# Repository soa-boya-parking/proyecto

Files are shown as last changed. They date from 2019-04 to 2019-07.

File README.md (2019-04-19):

# Proyecto Sistemas Operativos Avanzados 1C 2019 

### Integrantes

- Ezequiel Laurenti - 39245012
- Hector Rojas Stoll - 94448064
- Juan Jose Tocino - 38617339
- Damian Vinci - 30603450

## Proyecto Pileta   

El proyecto consiste en un administrador de pileta inteligente, que brindará lo siguiente:
- Detección del ingreso de un elemento a la misma y alerta del suceso.  
Esto es útil, por ejemplo, para detectar la caída accidental de una mascota a la pileta.  
- Detección de las condiciones de la pileta (temperatura) y por consiguiente dispensar la cantidad de cloro necesario
- Detección de lluvia:
  - De forma anticipada: Mediante la consulta a un servicio climatológico.
  - De forma nativa: Mediante la detección de gotas de lluvia.  
  En ambos casos será para activar un motor que despliegue una lona sobre la pileta.
- Detección de suciedad de la pileta.  

En cualquiera de los casos anteriores, se notificará mediante algunas de las conexiones disponibles (WiFi / Bluetooth)   
del suceso ocurrido.  
De cualquier manera, el usuario podrá configurar distintos parámetros manualmente desde su celular para modificar el funcionamiento, por ejemplo, la cantidad de cloro dispensada dependiendo de la cantidad de personas en la pileta.

## Especificaciones Técnicas 

**Las herramientas y tecnologías a utilizar serán:**

- SoC SparkFun ESP32
- BLE (Bluetooth Low Energy)
- Wifi (802.11 b/g/n/e/i WLAN)
- iPhone (con iOS 12.2)

**Sensores:**
 - Sensor de temperatura (DS18B20) A Prueba de agua.
 - Sensor de lluvia (FC-37 / YL-83).
 - Sensor de color (TCS3200 / TCS34725).
 - Acelerómetro (ADXL335).
 
 **Actuadores:**
  - Valvula Solenoide.
  - Buzzer.
  - Motor.

## Cerradura Electrónica  

El proyecto consiste en el control de las puertas de un hogar / establecimiento sin la utilización de llaves físicas.  
Entre las principales funciones del control de las puertas del hogar se encuentran:
- Detección del estado de la/s puerta/s (abierta - cerrada) 
- Apertura y/o cierre de la/s puerta/s 
- Programación del cierre y/o apertura de la/s puerta/s a un determinado horario.
- Apertura de la puerta por proximidad mediante un dispositivo asociado.
- Informe sobre un intento no autorizado y/o violento.

Todas las acciones anteriores serán accedidas mediante un dispositivo asociado (celular)   
de forma inalámbricamente (Wifi y Bluetooth)

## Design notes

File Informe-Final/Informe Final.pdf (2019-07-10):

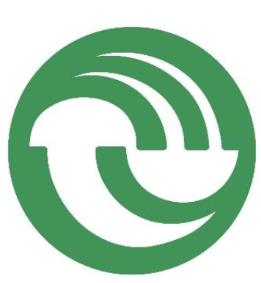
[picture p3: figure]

# Universidad Nacional de La Matanza

## Departamento de Ingeniería e Investigaciones Tecnológicas

# Sistemas Operativos Avanzados Proyecto Boya-Parking

# Informe Final

# Docentes:

## - Graciela de Luca - Waldo A. Valiente - Sebastián Barillaro - Mariano Volker - Carnuccio, Esteban Andrés - Gerardo Garcia

# Integrantes:

## - Héctor Rojas Stoll - Juan Jose Tocino - Ezequiel Laurenti - Damián Vinci

Índice

# Motivación del proyecto

La administración desatendida de una piscina mediante el uso de una boya inteligente y un dispositivo móvil, buscando ayudar al usuario final en la toma de decisiones al momento de realizar tareas de mantenimiento. Además, permitirá la automatización de determinadas funciones, delegando completamente la responsabilidad a la boya inteligente. La misma tendrá la capacidad de ejecutarlas en base a información recolectada del entorno mediante diversos sensores y además “aprendiendo” sobre condiciones pasadas, se espera que pueda cumplir los siguientes objetivos:

## - Apertura y / o cierre del techo de la piscina

- Automáticamente, dependiendo de los factores climatológicos.
- A demanda y de forma remota, a través de un dispositivo móvil.

## - Dispensación de cloro - De manera automática en un horario fijado por el usuario, en base a condiciones como temperatura actual, capacidad de la pileta siempre

y cuando se detecte a la pileta vacía (Sin personas dentro).
- A demanda y de forma remota, a través de un dispositivo móvil.
- Recibir alertas a un dispositivo móvil sobre la caída de un objeto a la piscina.

## - Monitoreo desde el dispositivo móvil en tiempo real del estado de la piscina

como la temperatura y el nivel de opacidad del agua.

# Software Utilizado

## - Arduino IDE 1.8.9 (C / C++) - Xcode 10.2.1 (Swift 5) - Servidor Web Lampp PHP 7 (Api Clima Mock)

# Componentes

# SoC (System on Chip)

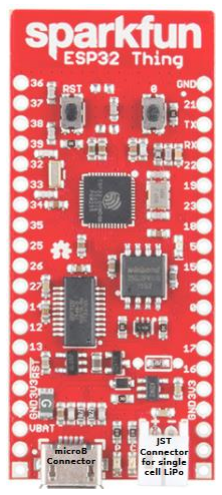
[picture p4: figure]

- Dual-core Xtensa 32-bit LX6 240MHZ.
- 520kB internal SRAM.
- 4MB external flash.
- Wireless 802.11 b/g/n/e/I WPA/WPA2.
- Bluetooth 4.2 / BLE.
- VCC Range: 2.2V ~ 3.6V.
- SPI, I2C, ART, I2S Interfaces.

# Sensores

## Acelerómetro ADXL345 (Digital)

- Sensor micromecanizado (MEMS) capacitivo.
- 3 ejes independientes.
- Compatibles con interfaces SPI y I2C.
- Rango de medición ajustable ±2g, ±4g, ±8g, ±16g.

## Colorímetro TCS34725 (Digital)

- Sensor de color digital.
- Proporciona los valores RGB y clear medición sin filtrar.
- Compatible con interfaz I2C.

## - Cuenta con un rango dinámico 3,800,000:1

## Sensor de temperatura DS18B20 Versión Sonda Impermeable (Digital)

- Sensor de temperatura digital.
- Rango de temperaturas: -55°C hasta los 125°C.
- Compatible con interfaz 1-wire (Un solo pin de datos).

## - Precisión ±0.5°C desde -10°C a +85°C

## Sensor detector de lluvia FC-37 (Digital / Analógico)

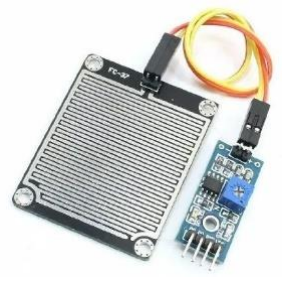
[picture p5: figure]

## - Sensor de detección de agua por variación de

conductividad.
•Permite la lectura de forma analógica o digital. •Posee dos partes el sensor y el controlador.

# Actuadores

## Motor DC RE280

- 9000 revoluciones por minuto.
- Tensión de trabajo 1.5V ~ 3V.

## Doble Puente H Driver L9110s

- Puede manejar 2 motores simultáneamente.
- Basado en el microcontrolador L9110.

## Electroválvula

- Tensión de trabajo 220V.
- Tipo normal – cerrada.

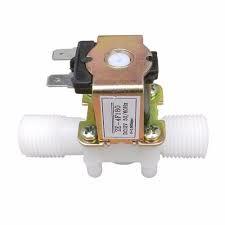
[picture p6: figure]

## Otros Relé El relé es un dispositivo electromagnético. Funciona como un interruptor controlado por un circuito eléctrico en el que, por medio de una bobina y un electroimán, se acciona un juego de uno o varios contactos que permiten abrir o cerrar

otros circuitos eléctricos independientes.

## Transistor El transistor es un dispositivo electrónico semiconductor utilizado para entregar una señal de salida en respuesta a una

señal de entrada.

## Resistor El resistor es un componente electrónico diseñado para introducir una resistencia eléctrica determinada entre dos

puntos del circuito eléctrico.

## Protoboard Es un tablero con orificios que se encuentran conectados eléctricamente entre sí de manera interna, en el cual se pueden insertar componentes electrónicos y cables para el

armado y prototipado de circuitos electrónicos.

# Diagramas Diagrama Fritzing

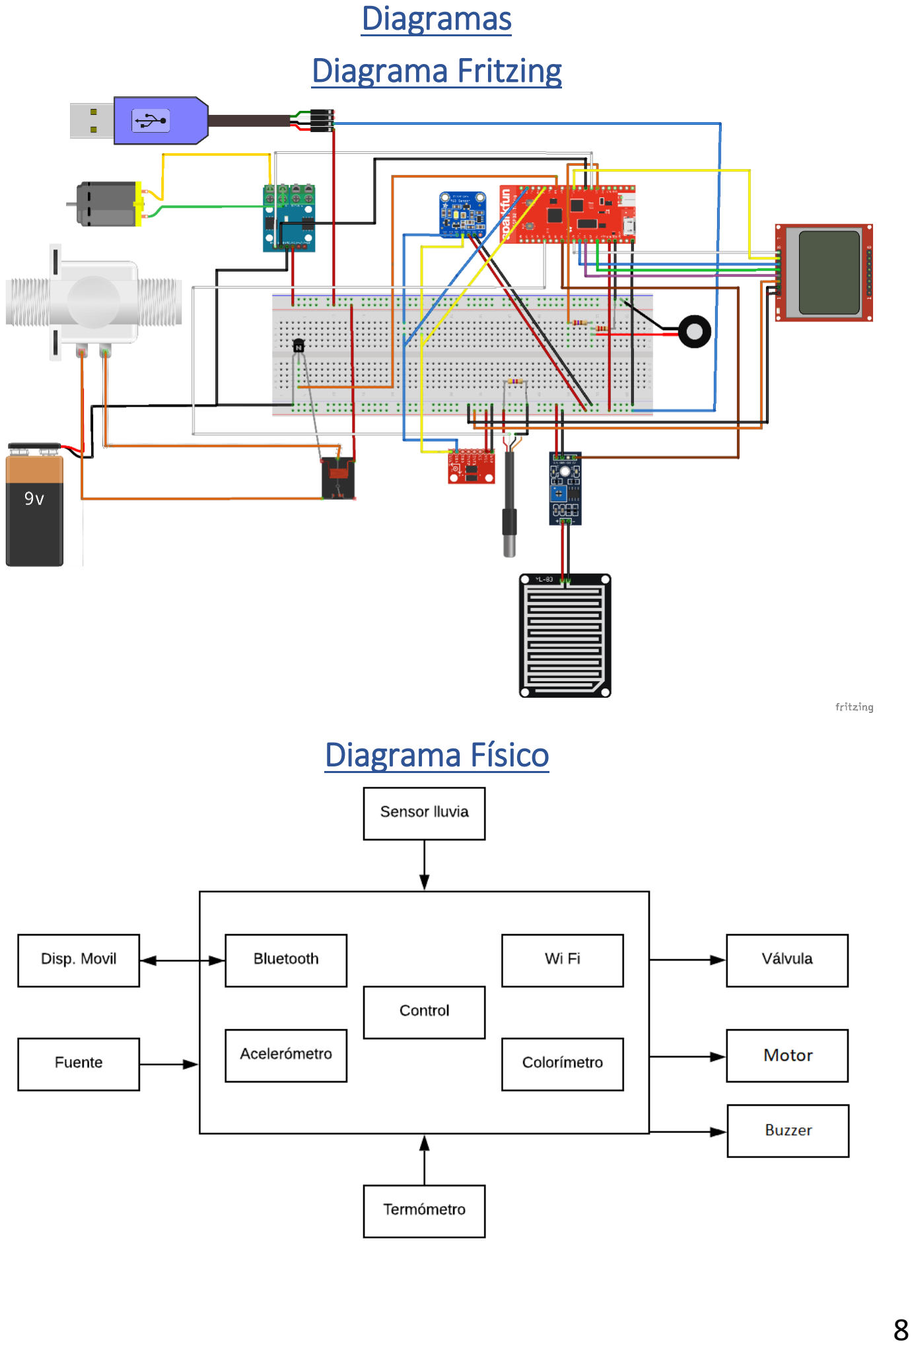
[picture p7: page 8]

# Diagrama Físico

# Diagrama Funcional

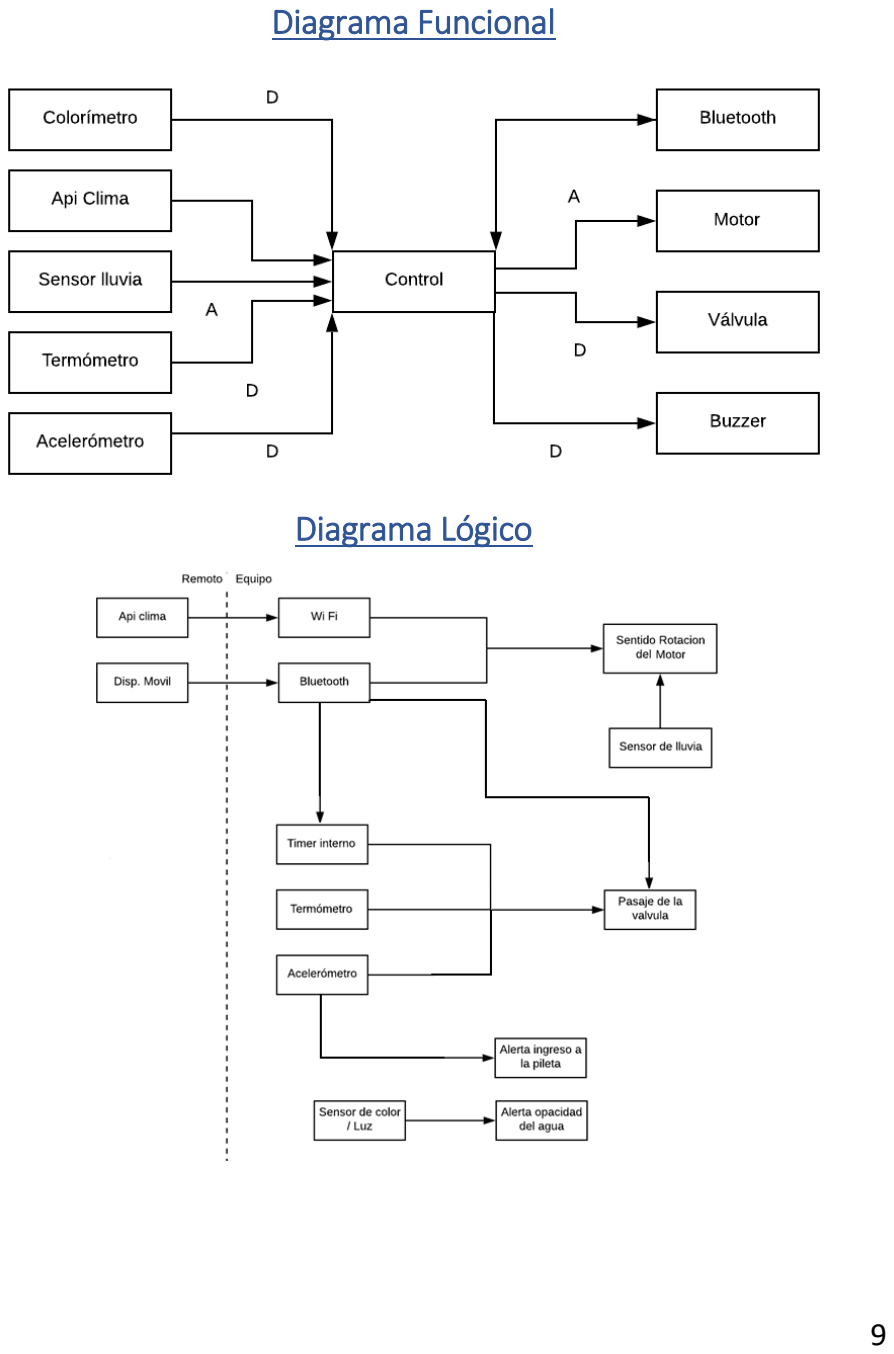
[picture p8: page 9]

# Diagrama Lógico

# Diagrama de software

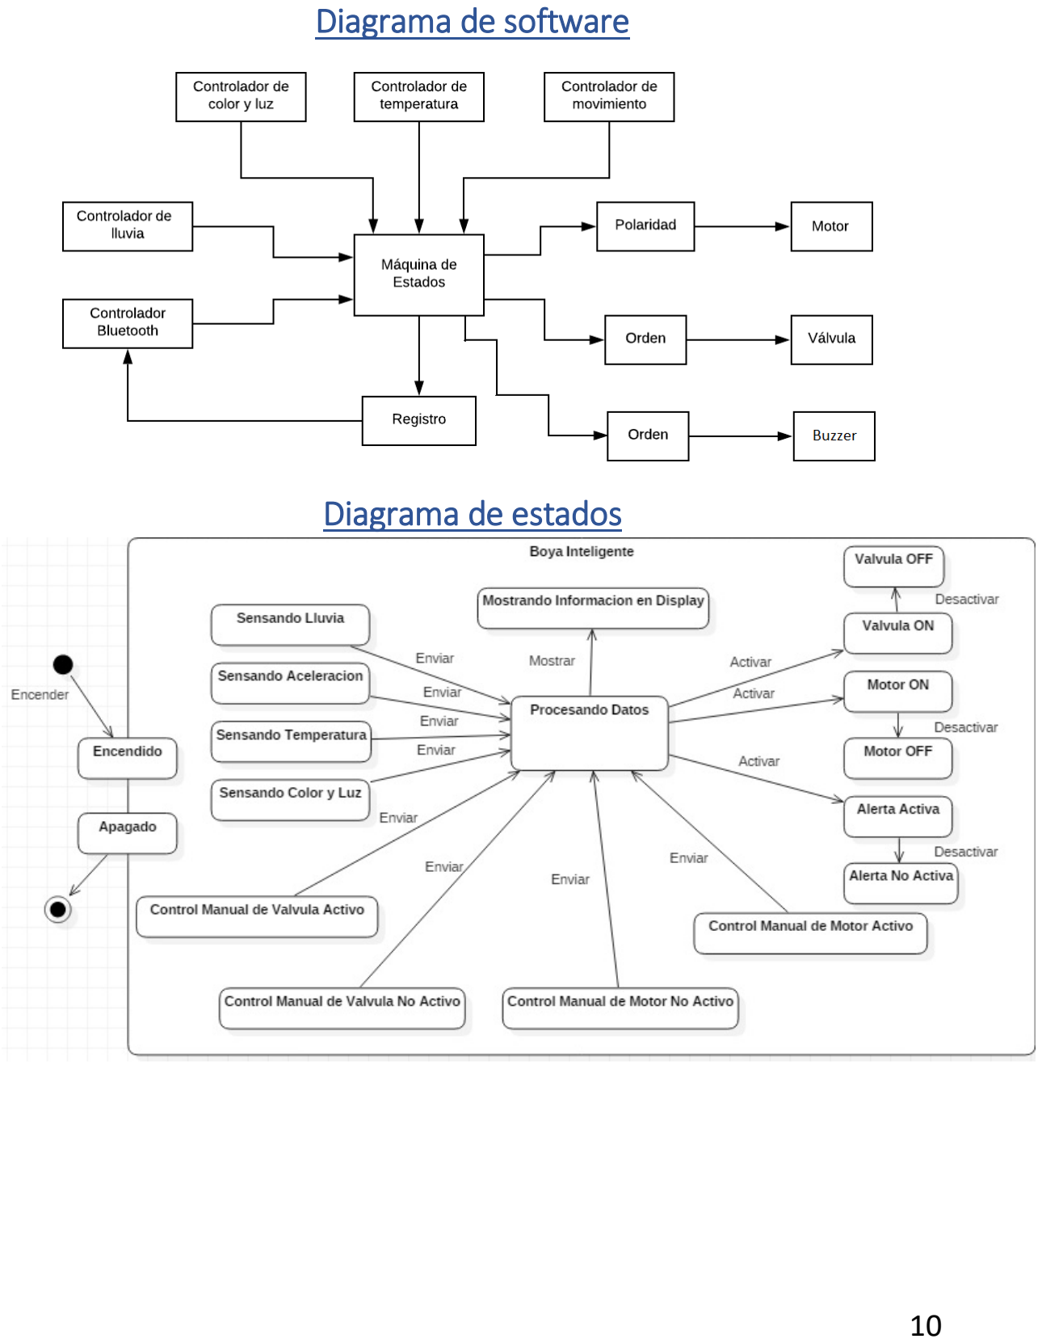
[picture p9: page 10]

# Diagrama de estados

# Diagrama En Bloques

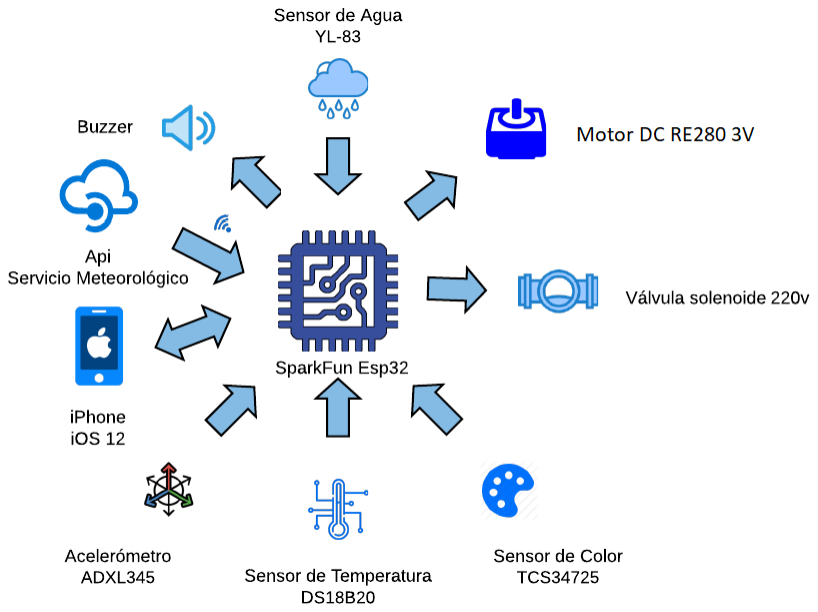
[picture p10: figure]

# Pantallas Pantalla del SE (Inicial)

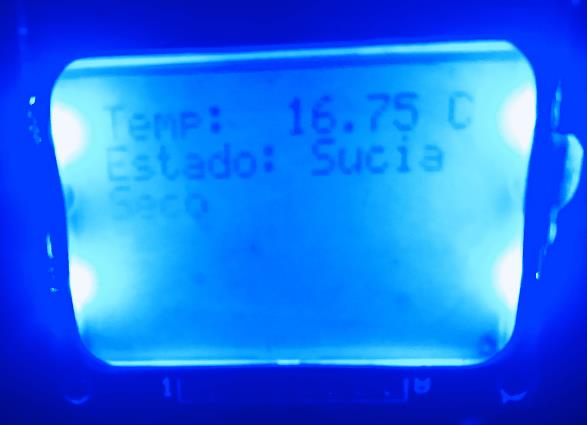
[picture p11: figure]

# Pantalla del SE (Reloj - Ubicación - Coordenadas)

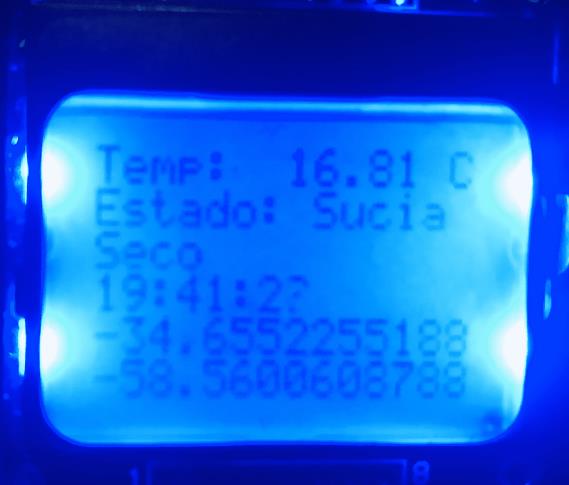
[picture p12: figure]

# Pantalla del SE (Reloj - Ubicación – Texto - Clima)

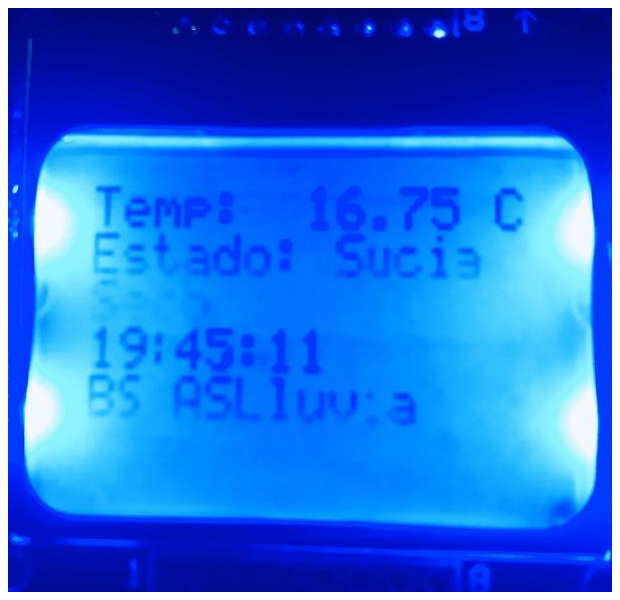
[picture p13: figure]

# Pantalla Principal de la Aplicación Mobile

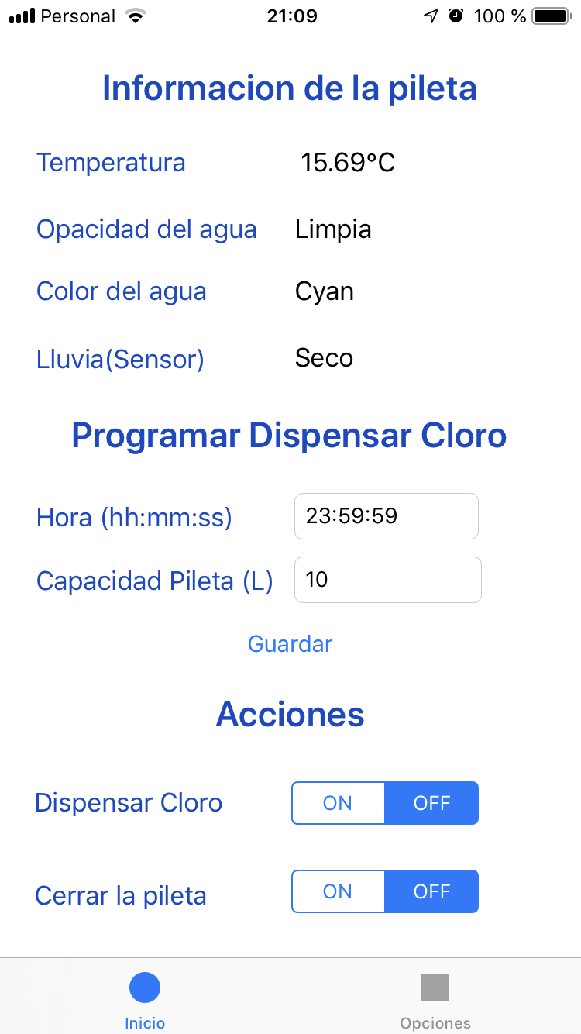
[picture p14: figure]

# Pantalla Secundaria de la Aplicación Mobile

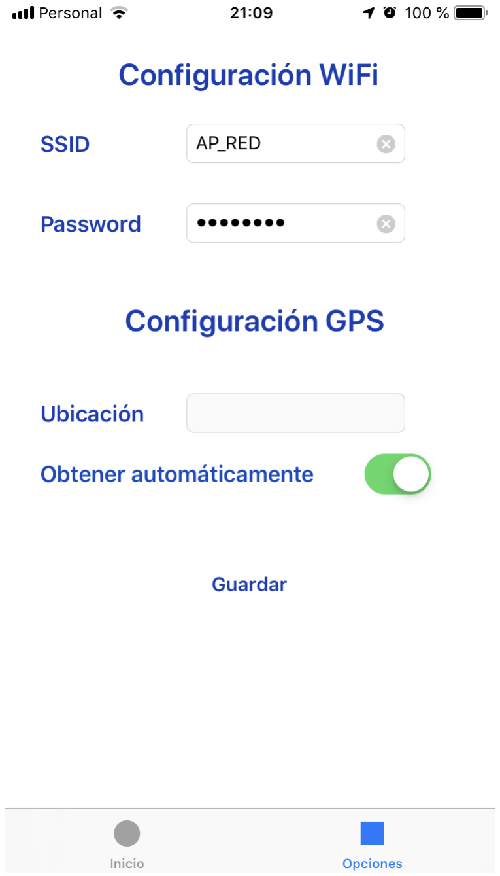
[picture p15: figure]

# Uso general y funcionalidades

## Una vez la Boya Inteligente se encuentre sumergida en la piscina, deberá activar el Bluetooth (obligatorio) en su dispositivo móvil y abrir la Aplicación Mobile. En la sección “Dispensar Cloro” de la Pantalla Principal, configurar los siguientes parámetros:

## - Hora: Horario preferido para el dispensado automático de cloro, deberá estar formateado con dos dígitos para la hora, dos para los minutos y dos para los segundos, separados por ‘:’ (dos puntos) (hh:mm:ss) - Capacidad Pileta: Capacidad (en Litros) de la piscina en la cual se encuentra

sumergida actualmente la Boya Inteligente.

## Adicionalmente, tendrá la posibilidad de cargar las siguientes configuraciones en la Pantalla Secundaria, necesarias para que la Boya Inteligente realice consultas periódicas del clima basándose en su ubicación actual:

## - Wifi: acceso a internet

- Ubicación: puede provenir del GPS interno del celular o texto plano.

## Cabe aclarar que el enlace Bluetooth entre la Boya Inteligente y el dispositivo móvil se efectuará automáticamente al iniciar la Aplicación Mobile con dicha

función encendida.

## Una vez terminada la parametrización inicial desde la Aplicación Mobile, tendrá a disposición las siguientes funciones:

## - Funciones automáticas: - Apertura o cierre del techo de la piscina: al detectar agua mediante su sensor de lluvia o una indicación de lluvia enviada desde la API del clima basada en su ubicación actual, la Boya Inteligente enviará una

orden al motor (Puente H) de cerrado de la piscina.

## - Alerta de caídas: al detectar un movimiento inusual, a partir de mediciones del acelerómetro catalogado como caída, la Boya Inteligente envía una alerta vía bluetooth al dispositivo móvil del

usuario (previamente vinculado).

## - Monitor de piscina: tendrá a su disposición el estado actual de la piscina, actualizado en tiempo real por la Boya Inteligente, tanto en la Pantalla Principal de la Aplicación Mobile (actualizada vía

Bluetooth), como en la pantalla presente en la Boya (temperatura, suciedad, color del agua y hora actual).

## - Dispensación de cloro: basándose en la configuración de dispensación, la Boya Inteligente dispensará el cloro en el horario preferido por el usuario. En caso de detectar movimiento en la

piscina durante dicho horario, postergará por una hora dicha función.

## Si esto ocurre durante tres días consecutivos y el usuario intenta modificar el horario de dispensación por uno concurrido, se mostrará la siguiente alerta:

## - Funciones a demanda:

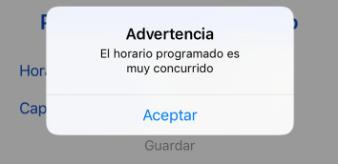
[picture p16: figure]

## - Apertura o cierre del techo de la piscina: El techo de la piscina es abierto o cerrado en cualquier momento desde la Pantalla Principal

de la Aplicación Mobile.

## - Dispensación de cloro: El usuario puede dispensar cloro en cualquier

momento desde la Pantalla Principal de la Aplicación Mobile.

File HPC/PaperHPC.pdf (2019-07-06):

## Reconocimiento de objetos con GPU en Boya inteligente

Hector Rojas Stoll¹
, Juan Tocino, Ezequiel Laurenti, Damian Vinci

1Universidad Nacional de La Matanza,
Departamento de Ingeniería e Investigaciones Tecnológicas, Florencio Varela 1903 - San Justo, Argentina Hector.rojass18@gmail.com, tocino.juan@gmail.conm, ezee.laurenti@gmail.com, damianvinci@gmail.com

Resumen. Este trabajo de investigación intenta comprobar si es posible utilizar reconocimiento de objetos en nuestro proyecto de Boya inteligente a través de imágenes captadas por una camara integrada a la boya y de esta manera poder dar avisos en su correspondiente aplicación de android “BoyApp” sobre la presencia de objetos en una pileta, utilizando procesamiento en paralelo con GPU.

Palabras claves: Boya inteligente, BoyApp, HPC, GPU, OpenCV, Object Recognition, Reconocimiento de objetos.

### 1 Introducción

Esta investigación se basa en añadir a nuestro proyecto Boya inteligente, que consiste en realizar distintas mediciones tales como temperatura, opacidad o movimiento en una pileta que nos den una idea sobre el estado en tiempo real de la misma para poder tomar una decisión y realizar una acción de forma remota desde una aplicación movil o que la haga el embebido de forma automática y poder mantener siempre la pileta en optimas condiciones, una nueva funcionalidad que haga uso de computación de altas prestaciones (HPC) y base su solución en alguno de los paradigmas vistos en clase (OpenCL, MPI o GPU).
En nuestro caso, haremos uso del módulo GPU integrado en nuestro dispositivo Android, que a través del procesamiento de imágenes e información de forma paralela nos permitirá saber en tiempo real, si existen objetos en el fondo de la pileta brindandonos además información de los mismos, y a su vez, le da al usuario la posibilidad de seguir utilizando las funcionalidades convencionales de la app y la boya sin afectar la performance o tiempos de respuesta.
La motivación del desarrollo de esta nueva funcionalidad es por un lado saber sobre la acumulación de agentes externos que colaboran con la descomposición del agua tales como algunos insectos, moluscos o incluso hojas, sobre todo en epoca otoñal, y por otro lado la detección de objetos personales que a las personas se les suelen caer y perder dentro del agua como por ejemplo joyas las cuales son importantes ubicar y recuperar rápido.
El tema del análisis de imágenes para la detección y obtención de informacion de objetos es un tema que se viene desarrollando desde hace tiempo y ya existen aplicaciones que cumplen estan funciones, por ejemplo una de las formas mas básicas de reconocimiento de imágenes es el codigo de barras que se comenzó a utilizar para el reconocimiento de objetos en almacenes e industrias y mas tarde se haría popular su uso en supermercados. Luego surgió el codigo bidimensional (QR) que permite almacenar mucha mas información que un codigo de barra, hasta llegar a hoy en ía en donde una de las aplicaciones más populares de reconocimiento de imágenes en dispositivos móviles es la aplicación de Google: Google Lens [1], la cual es capaz de, al hacer una fotografía, reconocer ciertas imágenes que aparecen en ella, pero está a diferencia de nuestro proyecto, sube la imagen a servidores en la nube donde se la procesa, se extrae información de ella y se hace una consulta en el motor de búsqueda al respecto pudiendo reconocer además de objetos, texto, códigos de barra y QR, etc.

### 2 Desarrollo

Para aplicar la funcionalidad propuesta en esta investigación, como primer medida, necesitaremos integrar a la boya una cámara como medio de obtencion de información, para que, de esta manera, paralelamente se pueda procesar la misma y llevar a cabo el reconocimiento del objeto.
Las imágenes captadas por la cámara son enviadas a la placa Arduino a la cual estará conectada, y luego serán enviadas al dispositivo móvil donde las imágenes seran procesadas y analizadas mediante el modulo GPU con el fin de detectar la presencia de algún objeto en el fondo de la pileta, este módulo además mediante algoritmos de reconocimiento de patrones y puntos característicos comparará esta información con otra almacenada en una base de datos que implementaremos y donde se encontrarán imágenes de posibles obejtos que se puedan encontrar en una pileta generalmente, con su respectiva información.
Finalmente, una vez reconocido el objeto, en el caso de tratarse de hojas o bichos solo se enviará una notificacion al dispositivo móvil avisando de la presencia del mismo, y en caso de tratarse de objetos personales o no identificados se procederá además a enviar la imagen del mismo acompañado de su información en caso de tenerla, para que el usuario sepa de antemano si solo necesita limpiar o el fondo o se trata de la detección de ese objeto perdido tiempo antes por él o alguien mas y realizar la acción correspondiente.
El diseño implementado permitirá que toda esta dinámica se haga en el dispositivo, sin tener que acceder a Internet para ello, y devolviendo resultados en un tiempo aceptable para el usuario, para lo cual utilizaremos algoritmos basados en el uso de técnicas para el reconocimiento de imágenes tales como puntos característicos o keypoints y descriptores.

Un punto característico es un lugar concreto de una imagen que contiene una propiedad que la define. Esto puede ser, por ejemplo, esquinas, bordes, formas u otros elementos que representen una particularidad de la imagen. Existen multitud de tipos de puntos característicos, entre ellos SIFT y SURF, que son los más extendidos, y otros como los BRIEF o KAZE que por sus características, son menos eficientes en su funcionamiento, aunque usados en ocasiones concretas [2]. Una vez extraídos los puntos característicos, se genera un descriptor para cada uno de ellos. Los descriptores son estructuras que contienen varios datos sobre el punto y su entorno, para poder definir un contexto para el mismo. Idealmente, estos descriptores deben ser invariantes a la escala, traslación o rotación de la imagen, así como cambios de iluminación o ruido. Otro de los tipos de punto y descriptor más conocidos son los tipo ORB (Oriented FAST and Rotated BRIEF) [3], la combinación de FAST y BRIEF, el cual podría plantarle cara a los puntos SIFT y SURF en cuestión de eficiencia y precisión.
En nuestro proyecto se utilizaran los puntos y descriptores ORB, ya que ofrecen ciertas ventajas:
1. Son más rápidos en su procesamiento, ya que sus descriptores son binarios.
2. En cuestión de precisión, son equivalentes a SIFT y SURF, que son los más extendidos.
3. ORB es de uso libre, mientras que SIFT y SURF operan bajo derechos de autor.

3 Explicación del algoritmo.

En primera instancia se realiza el emparejamiento de puntos, proceso mediante el cual los descriptores de dos imágenes son comparados y unidos en parejas. Existen varios métodos para este proceso, el más sencillo es el del vecino más próximo, dónde se calcula la distancia entre los descriptores y se emparejan con el más cercano.
Una vez se tienen los puntos emparejados, se busca una homografía que transforme los puntos de la primera imagen en la segunda. Una homografía es una transformación proyectiva entre dos figuras geométricas planas. En general se consideran que dos imágenes son equivalentes si existe dicha transformación. Para determinar los parámetros de la transformación, normalmente se utilizan sólo unas pocas parejas de puntos. La transformación resultante se aplica al resto de puntos, comparando el punto transformado con el punto emparejado. La homografía debe ser independiente del tamaño, localización y rotación del objeto de la escena. Este procedimiento es usado para comprobar qué cantidad de puntos de la imagen de entrada pertenecen a la imagen de la base de datos y si estos coinciden. Si se dispone de las suficientes parejas buenas, la imagen ha sido reconocida.
Para poder hacer programas utilizando los procedimientos descritos en este apartado, se utilizará la interface de Android de OpenCV [4], diseñado para la eficiencia computacional con fuerte enfoque en aplicaciones de tiempo real, del cual utilizaremos concretamente sus funciones relativas al tratamiento de imágenes (como pasar de una foto en color a otra en escala de grises) y funciones para la extracción de puntos característicos, así como sus descriptores, emparejamientos, homografía y vecinos más próximos [5].
Además debido a que necesitamos paralelizar el trabajo para agilizar los tiempos de procesamiento, será necesario aplicar la arquitectura CUDA (Arquitectura Unificada de Dispositivos de Cómputo) [6], que hace referencia a una plataforma de computación en paralelo (https://es.wikipedia.org/wiki/Computaci%C3%B3n_paralela) incluyendo un compilador (https://es.wikipedia.org/wiki/Compilador) y un conjunto de herramientas de desarrollo creadas por nVidia (https://es.wikipedia.org/wiki/NVidia) que permiten a los programadores codificar algoritmos en GPU (https://es.wikipedia.org/wiki/GPU) [7].

El siguiente código ejemplifica el uso de CUDA con el algoritmo ORB.

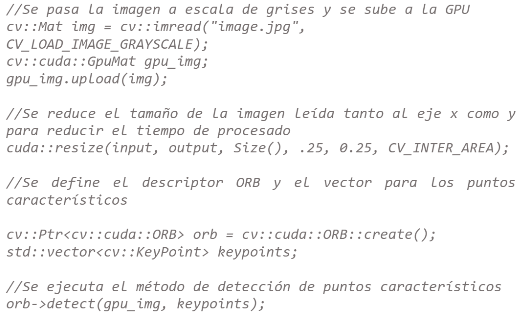
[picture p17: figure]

En este ejemplo se aplica paralelismo al trabajar con la imagen, lo cual será necesario ya que al ser imágenes tomadas bajo el agua se necesitará de mucha resolución de la cámara, lo que se traduce en más pixeles a analizar y por lo tanto más carga computacional, y luego se utiliza el algoritmo ORB para detectar los keypoints necesarios para realizar la comparación con otra imagen.
En cuanto a la GPU utilizaremos una configuración de bloques-hilos de (32x32) y una configuración de grilla-bloques de (69x69) por lo cual tendremos 1024 hilos por bloque y 4761 bloques por grilla, y la cámara que necesitaremos tendrá una resolución 4K (3.840x2.160 pixeles), es decir un total de 8.294.400 pixeles.
Ya que las imágenes serán procesadas por el GPU pixel a pixel, se trabajara cada pixel en un hilo distinto, por lo cual en cada bloque de la grilla puedo procesar 1024 pixeles de mi imagen, lo que nos dara un total de 8100 bloques y 2 grillas para la totalidad de la imagen.

### 4 Pruebas que pueden realizarse

Las pruebas que podrían realizarse para verificar el correcto funcionamiento de esta función implican arrojar diferentes objetos al fondo de la pileta, ya sean las que están cargadas en nuestra BD como otros que no lo estén, a partir de esto la boya debería detectar la presencia de los mismos enviando la correspondiente notificación al dispositivo móvil con un aviso, una imagen del objeto con o sin información adicional según corresponda.

### 5 Conclusiones

A través de esta investigación intentamos demostrar que se puede implementar el reconocimiento de objetos mediante la integración de una cámara en nuestro proyecto Boya inteligente, la utilización de las funciones de la librería OpenCV para Android y el modulo GPU de nuestro dispositivo móvil.
A partir de esta experiencia pudimos aprender sobre los grandes beneficios que conlleva la utilización de HPC a la hora de desarrollar un software que sea paralelizable, con alta demanda de poder de cómputo, con algoritmos muy complejos o neceidad de mucha memoria o ancho de banda, concluyendo que es una solución viable en cuanto a lo tecnológico y económico para tomar en cuenta en futuros proyectos.
Una mejora a futuro podría ser optimizar la función de comparación de la imagen recibida con las imágenes de la BD, ya que mientras la cantidad de imágenes sea baja no habrá problema, pero si esta empieza a crecer puede que se tarde un tiempo en realizar el proceso, para ello en vez de llamar a la función de comparación por cada imagen, arrancaría un hilo, que sería el encargado de realizar la tarea. Por tanto, se lanzarían tantos hilos como imágenes contenga la base de datos.

### 6 Referencias

1. Google Lens, https://lens.google.com/ [1].
2. Ebrahim Karami, Siva Prasad, Mohamed Shehata: Image Matching Using SIFT, SURF, BRIEF and ORB: Performance Comparison. St Johns, Canada (2015) [2].
3. Ethan Rublee, Vincent Rabaud, Kurt Konolige, Gary Bradski.: ORB: an efficient alternative to SIFT or SURF (2015) [3].
4. OpenCV, https://opencv.org/android/ [4].
5. I. Culjak, D. Abram, T. Pribanic, H. Dzapo, M. Cifrek: A brief introduction to OpenCV. Publisher: IEEE (2015) [5].
6. CUDA, https://developer.nvidia.com/cuda-toolkit [6].
7. F. Aguilera, J. Aceves, S. Arguelles, E. Gomez, G. Martinez: Utilizacion de GPU-CUDA en el Procesamiento Digital de Imágenes (2015) [7].

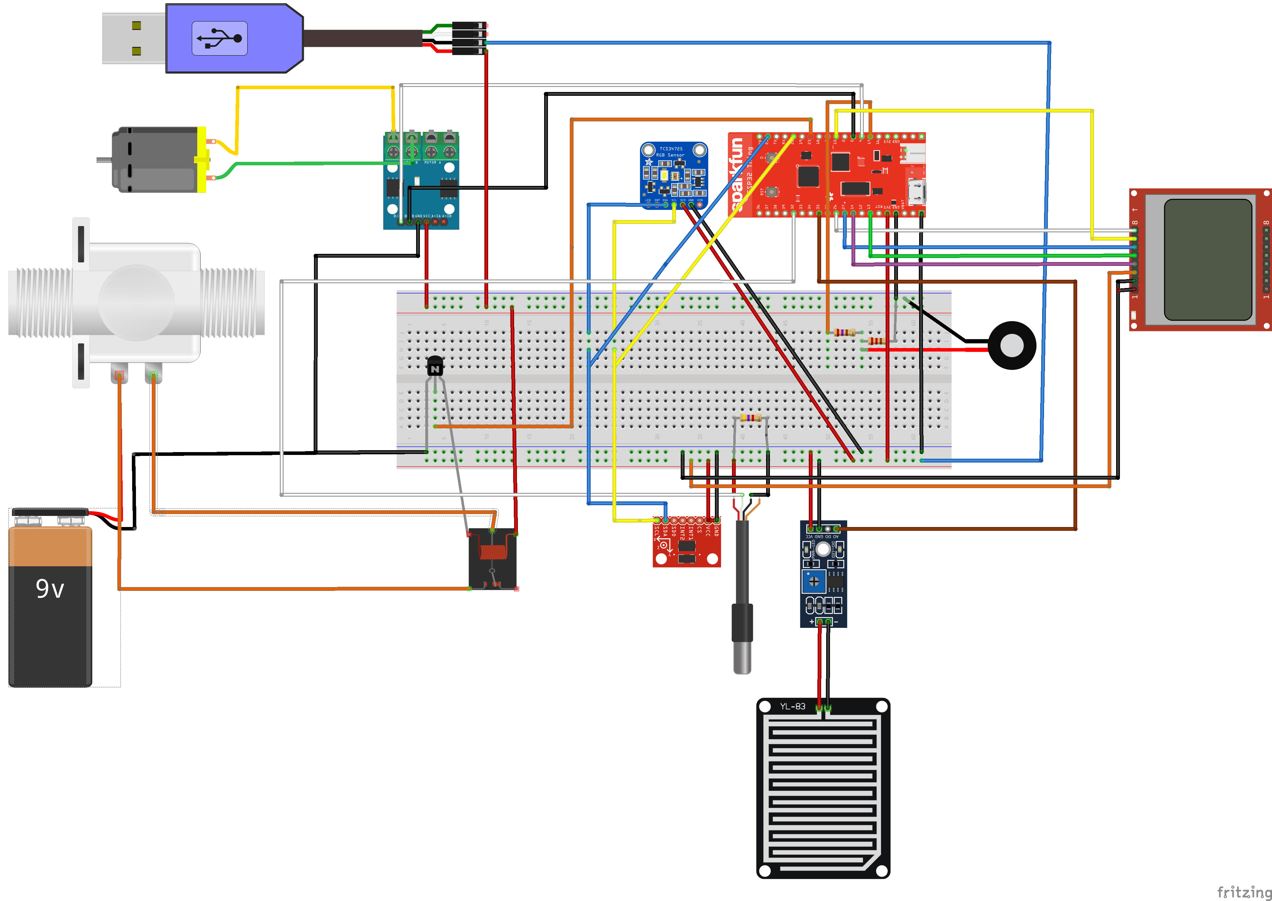
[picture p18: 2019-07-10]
Sistema-Embebido/DiagramasFinal/Fritzing.png

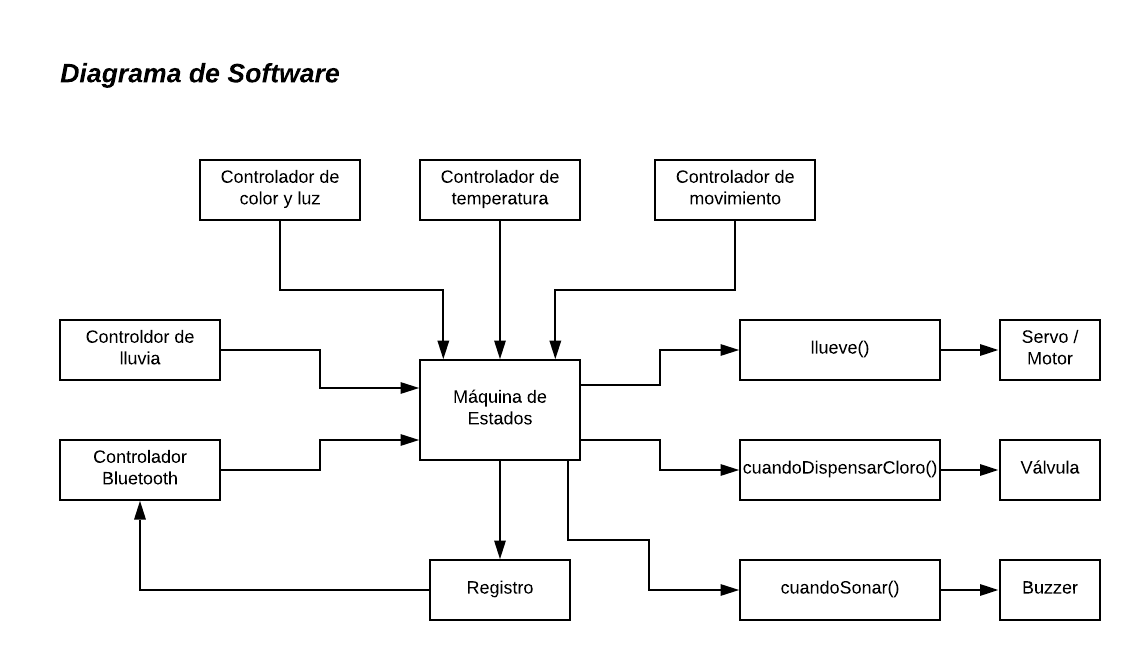
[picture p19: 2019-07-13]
Sistema-Embebido/DiagramasFinal/Diagrama de Software.png

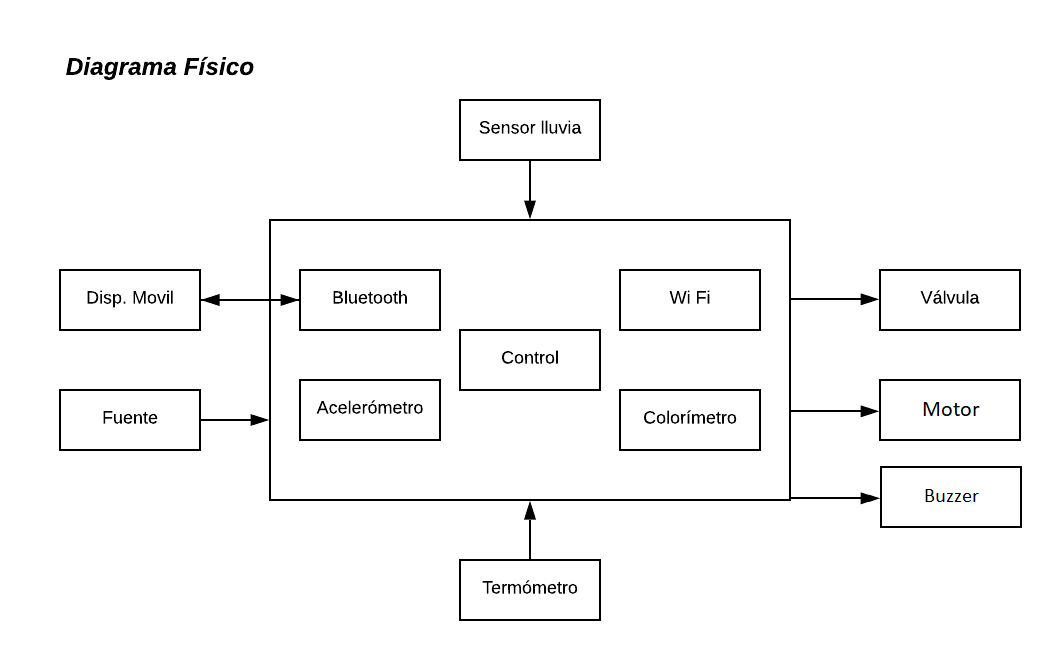
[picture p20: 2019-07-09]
Sistema-Embebido/DiagramasFinal/Diagrama Fisico.png

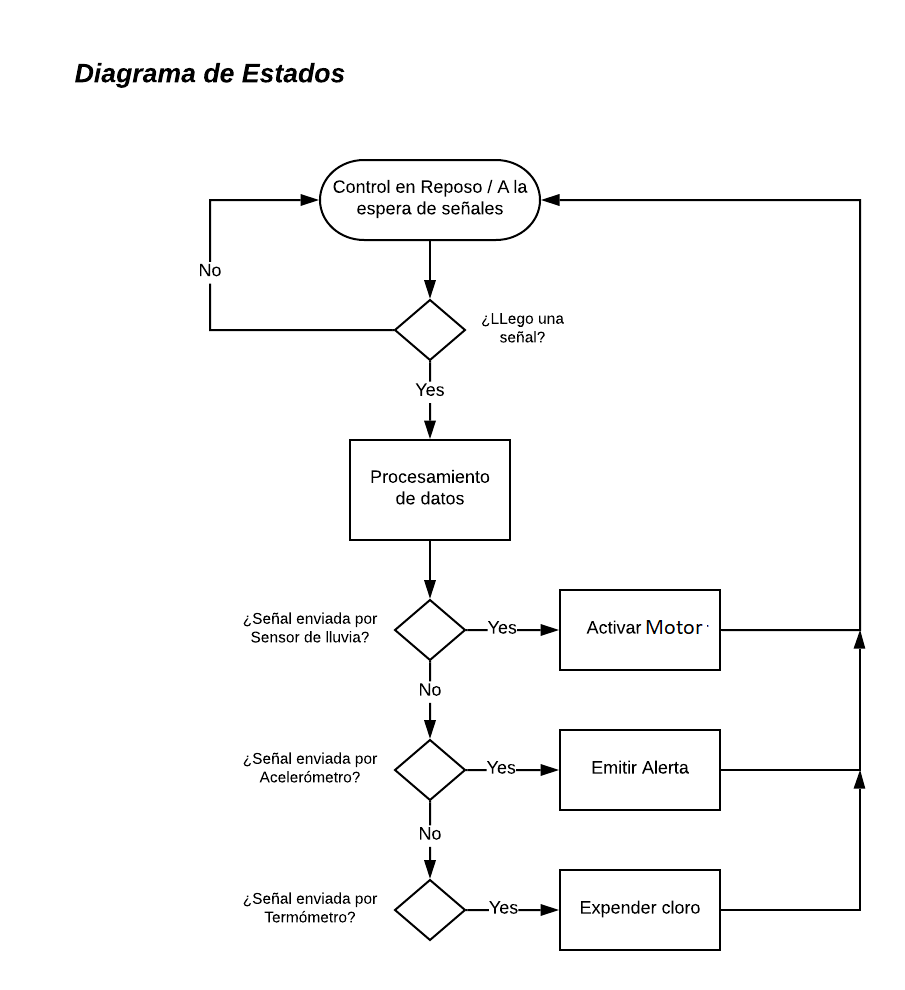
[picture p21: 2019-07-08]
Sistema-Embebido/DiagramasFinal/Diagrama De Estados.png

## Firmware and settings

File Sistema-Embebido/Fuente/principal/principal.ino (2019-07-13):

#include "parametros.h"

//Inicializaciones.
void setup() 
{
  //-------INICIALIZACION DE PANTALLA.
  gpio_set_direction(GPIO_NUM_23, GPIO_MODE_OUTPUT);
  gpio_set_level(GPIO_NUM_23, 1);
  lcd.begin(PANTALLA_COLUMNAS, PANTALLA_FILAS);
  lcd.clear();
  lcd.setContrast(PANTALLA_CONTRASTE);
  
  //Velocidad puerto serial.
  Serial.begin(SERIE_VELOCIDAD);

  //-------INICIALIZACION DEL TERMOMETRO. 
  tempSensor.begin();
  mostrar(0, 0, "DS18B20 ON");

  //-------INICIALIZACION DEL COLORIMETRO.
  tcs.begin();
  mostrar(0, 1, "TCS34725 ON");

  //-------INICIALIZACION DE ACELEROMETRO.
  adxl.powerOn();            
  adxl.setRangeSetting(16);
  mostrar(0, 2, "ADXL345 ON");

  //-------INICIALIZACION DEL BUZZER.
  pinMode(PINBUZZER, OUTPUT);

  //-------INICIALIZACION DE LOS PINES DEL PUENTE H(MOTOR).
  pinMode(BIA, OUTPUT);
  pinMode(BIB, OUTPUT);
  mostrar(0, 3, "Puente H ON");

  //-------INICIALIZACION DE LOS PINES DEL SENSOR DE AGUA.
  pinMode(PINAGUA, INPUT);
  mostrar(0, 4, "FC-37 ON");

  //-------INICIALIZACION DE LOS PINES DEL RELEE.
  pinMode(PINRELE, OUTPUT);
  digitalWrite(PINRELE, LOW);
  mostrar(0, 5, "Valvula ON");
  

  //-------INICIALIZACION DEL BLUETOOTH.
  // Inicializacion del BLE con nombre.
  BLEDevice::init("ESP32");

  // Creacion del servidor BLE.
  pServer = BLEDevice::createServer();
  pServer->setCallbacks(new Servidor());
  BLEService *pService = pServer->createService(SERVICE_UUID);
  pTxCharacteristic = pService->createCharacteristic(CHARACTERISTIC_UUID_TX,BLECharacteristic::PROPERTY_NOTIFY);          
  pTxCharacteristic->addDescriptor(new BLE2902());
  BLECharacteristic * pRxCharacteristic = pService->createCharacteristic(CHARACTERISTIC_UUID_RX,BLECharacteristic::PROPERTY_WRITE);
  pRxCharacteristic->setCallbacks(new Cliente());
  pService->start();
  pServer->getAdvertising()->start();
  mostrar(0, 5, "Bluetooth ON");

  adaptacionColor(r, g, b, c);
  
  //Asignacion de la tarea para el core 1. Recoleccion de datos de sensores.
  xTaskCreatePinnedToCore(Task1Core1, "Task1", STACK_SIZE_10000, NULL, 1, &Task1, X_CORE_ID_0);     

  //Asignacion de la tarea para el core 2. Entradas y salidas pantalla, bluetooth, wifi.
  xTaskCreatePinnedToCore(Task2Core1, "Task2", STACK_SIZE_5000, NULL, 1, &Task2, X_CORE_ID_1);  

  //La primera linea de la pantalla es el nombre del proyecto.
  //strcpy(l1, "Boya-Parking");
  //Delay de cinco segundos para mostra los mensajes de inicializacion.
  delay(5000);
}

//Esta funcion actualiza la informacion de los sensores, y la envia a las variables de pantalla.
void getSensores()
{
    //TEMPERATURA
    
    //Obtencion de la informacion del termometro, adaptacion y envio hacia las variables de pantalla.
    tempSensor.requestTemperatures();
    char tempchar[9]; char tempmsg[20] = "Temp: ";
    temperatura = tempSensor.getTempCByIndex(0);
    dtostrf(temperatura, 6, 2, tempchar);
    strcat(tempmsg, tempchar);
    strcat(tempmsg, " °C");
    strcpy(l1, tempmsg);
    
    //ACELEROMETRO
    
    //Obtencion de la informacion del acelerometro, adaptacion y envio hacia las variables de pantalla.
    char xx[5]; char yy[5]; char zz[5]; char acelmsg[20] = "X:";
    adxl.readAccel(&x, &y, &z);

    //COLORIMETRO

    //Obtencion de la informacion del colorimetro, adaptacion y envio hacia las variables de pantalla.
    tcs.getRawData(&r, &g, &b, &c);
    //Se calcula el colorTemp y lux en base a los parametros anteriores r, g, b.
    colorTemp = tcs.calculateColorTemperature(r, g, b);
    lux = tcs.calculateLux(r, g, b);
    //Se calcula la suciedad mediante pruebas caseras realizadas, teniendo en cuenta el colorTemp y lux.
    int suciedad = corroborarSuciedad(colorTemp, lux);
    if(suciedad == COLORIMETRO_ESTADO_AGUA_LIMPIA)
      strcpy(l2, "Estado: Limpia");
    else if(suciedad == COLORIMETRO_ESTADO_AGUA_ALGOSUCIA)
      strcpy(l2, "Estado: Normal"); //No alcanzan los caracteres en la pantalla para algo sucia
    else if(suciedad == COLORIMETRO_ESTADO_AGUA_SUCIA)
      strcpy(l2, "Estado: Sucia");  
    adaptacionColor(r, g, b, c);

    //SENSOR AGUA

    //Obtencion de la informacion del sensor de agua.
    valorSensorAgua = analogRead(PINAGUA);
    char agua[11] = "Agua: "; char a6[7];
    if(valorSensorAgua > SENSOR_LLUVIA_TOLERANCIA_SECO_LLOVIZNA)
      strcpy(l3, "Seco");
    else if(valorSensorAgua > SENSOR_LLUVIA_TOLERANCIA_LLOVIZNA_LLUVIA)
      strcpy(l3, "Llovizna");
    else
      strcpy(l3, "Lluvia");

    //BLUETOOTH PREPARACION + LOGICA INDEPENDIENTE

    //Preparacion de los datos por Bluetooth. (NO ENVIO)
    strcpy(datosBluetooth, tempchar);
    strcat(datosBluetooth, ";");
    
    if(suciedad == COLORIMETRO_ESTADO_AGUA_LIMPIA)
      strcat(datosBluetooth, "Limpia");
    else if(suciedad == COLORIMETRO_ESTADO_AGUA_ALGOSUCIA)
      strcat(datosBluetooth, "Algo Sucia");
    else if(suciedad == COLORIMETRO_ESTADO_AGUA_SUCIA)
      strcat(datosBluetooth, "Sucia");
      
    strcat(datosBluetooth, ";");
    
    if(valorSensorAgua > SENSOR_LLUVIA_TOLERANCIA_SECO_LLOVIZNA)
    {
      strcat(datosBluetooth, "Seco");
      lluvia = 0; //Esta variable es leida por el thread aparte de los sensores que determina si cerrar o no el techo.
    } 
    else if(valorSensorAgua > SENSOR_LLUVIA_TOLERANCIA_LLOVIZNA_LLUVIA)
    {
      strcat(datosBluetooth, "Llovizna");
      lluvia = 1;
    }
    else
    {
      strcat(datosBluetooth, "Lluvia");
      lluvia = 1;
    }
    
    strcat(datosBluetooth, ";");
    
    if(abs(x+y+z) - abs(xyz) > SENSIBILIDAD_ACELEROMETRO)
    {
      strcat(datosBluetooth, "ALERTA");
      hayAlgoEnPileta = 1;
    }
    else
    {
      strcat(datosBluetooth, "NADA");
      hayAlgoEnPileta = 0;
    }
    strcat(datosBluetooth, ";");
    strcat(datosBluetooth, nombreColor);
    strcat(datosBluetooth, ";");
    //Si el horario seleccionado por el usuario es muy concurrido en base a dias pasados para dispensar cloro.
    if(errorPorConcurrencia == 1)
    {
      strcat(datosBluetooth, "NOK");
      errorPorConcurrencia = 0;
    }
    else
      strcat(datosBluetooth, "OK");
    strcat(datosBluetooth, ";");
    xyz = x+y+z;
}

//Thread1-Core1
void Task1Core1(void* pvParameters)
{
  for(;;)
  {
    getSensores();
  }
      
}

//Thread2-Core2
void Task2Core1(void* pvParameters)
{
  TickType_t momentoDoInicio;
  momentoDoInicio = xTaskGetTickCount();
  for (;;)
  {
      vTaskDelayUntil(&momentoDoInicio,pdMS_TO_TICKS(1000));
      actualizarPantalla();
      enviarDatosBluetooth();
      actualizarHora();
      cuandoDispensarCloro();
      cuandoSonar();
      llueve();
      obtenerClima();
  }
}

//Sin uso por el uso de los dos nucleos.
void loop() 
{
}

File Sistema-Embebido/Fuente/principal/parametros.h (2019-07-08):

//-------LIBRERIAS

//Wifi y HTTPClient
#include "WiFi.h"
#include "HTTPClient.h"

//Bluetooth
#include <BLEDevice.h>
#include <BLEServer.h>
#include <BLEUtils.h>
#include <BLE2902.h>

//Termometro
#include "OneWire.h"
#include "DallasTemperature.h"

//Acelerometro
#include "SPI.h"
#include "Wire.h"
#include "SparkFun_ADXL345.h"

//Pantalla
#include "PCD8544.h"
#include "driver/gpio.h"
static PCD8544 lcd = PCD8544(14,13,27,26,15); //Pines SPI de la pantalla.

//Colorimetro
#include "Adafruit_TCS34725.h"
#include "ColorConverterLib.h"

//Motor - Puente H
#include <analogWrite.h>
const int BIA = 0;
const int BIB = 4;
byte speed = 255;

//Buzzer
const int PINBUZZER = 17;

//C
#include "stdlib.h"
#include "string.h"

//RELOJ
int relojActivado = 0;
unsigned long horaenSegundos = 0;
int segundosActuales = 0;
int minutosActuales = 0;
int horasActuales = 0;
//Por defecto a las 23:59:59 si no especifican.
int segundosProgramadosDispensarCloro = 23;
int minutosProgramadosDispensarCloro = 59;
int horasProgramadosDispensarCloro = 59;
int capacidadPileta = 0; // Capacidad de la pileta introducida por el usuario.
int lluvia = 0; //Si el sensor de lluvia detecta lluvia, esta variable cambia a 1 y viceversa.
int techocerrado = 0; //Si el techo ya fue cerrado no se vuelve a cerrar.
int coordenadas = 0; //Si la ubicacion es en base a las coordenadas del celular esta variable cambia a 1.
int const UNSEGUNDO = 1000;

//Constantes para mensajes Bluetooth
int const BLUETOOTH_LONGITUD_MENSAJE = 51;
int const ORDEN_CLORO = 1;
int const ORDEN_MOTOR = 2;
int const ORDEN_WIFIGPS = 3;
int const ORDEN_WIFIGPSCOORD = 5;
int const ORDEN_WIFIGPSCOORDRELOJ = 7;
int const ORDEN_PROGRAMARCLORO = 9;

//Constantes para el puerto serie.
int const SERIE_VELOCIDAD = 115200;

//Constantes para la pantalla.
int const PANTALLA_CONTRASTE = 50;
int const PANTALLA_COLUMNAS = 84;
int const PANTALLA_FILAS = 48;
int const PANTALLA_CARACTERES_POR_LINEA = 21;

//Constantes para la multitarea.
int const STACK_SIZE_10000 = 10000;
int const STACK_SIZE_5000 = 5000;
int const X_CORE_ID_1 = 1;
int const X_CORE_ID_0 = 0;

//Constantes para el sensor de lluvia.
int const SENSOR_LLUVIA_TOLERANCIA_SECO_LLOVIZNA = 4000;
int const SENSOR_LLUVIA_TOLERANCIA_LLOVIZNA_LLUVIA = 2500;

//Constantes para el colorimetro.
const int COLORIMETRO_ESTADO_AGUA_LIMPIA = 1;
const int COLORIMETRO_ESTADO_AGUA_ALGOSUCIA = 2;
const int COLORIMETRO_ESTADO_AGUA_SUCIA = 3;
const int COLORIMETRO_TOLERANCIA_COLOR_TEMP_LIMPIA = 12500;
const int COLORIMETRO_TOLERANCIA_COLOR_TEMP_ALGOSUCIA = 14500;
const int COLORIMETRO_TOLERANCIA_COLOR_LUX_LIMPIA = 12500;
const int COLORIMETRO_TOLERANCIA_COLOR_LUX_ALGOSUCIA = 12500;

//Constantes / Macros para el dispensado de cloro.
const int LIMITE_CONCURRENCIA = 3; //Si en 3 dias seguidos a la hora del dispensado de cloro la pileta estaba concurrida, ya no se podra seleccionar ese horario.
int errorPorConcurrencia = 0; //Si esta variable esta en una, el usuario debe seleccionar otro horario para el dispensado de cloro.
int concurrenciaPileta[24]= {0}; //Este vector guarda si para cada hora del dia, los anteriores dias estuvo muy concurrido a la hora de dispensar cloro.
#define FRIA (temperatura > 0 && temperatura < 15)
#define NORMAL (temperatura > 15 && temperatura < 20)
#define CALIENTE (temperatura > 20)

//-------CONFIGURACIONES GLOBALES (VARIABLES)

//Parametros de la conexion wifi.
char ssid[50] = "";
char password[50] = "";
const int WIFI_DELAY = 4000;
const char* WIFI_API_CLIMA = "http://191.238.213.18/obtenerClima.php?password=asd1234";

//Bluetooth
BLEServer *pServer = NULL;
BLECharacteristic * pTxCharacteristic;
bool deviceConnected = false;
bool oldDeviceConnected = false;
uint8_t txValue = 0;

//Estos numeros se frutean. https://www.uuidgenerator.net/
#define SERVICE_UUID           "6E400001-B5A3-F393-E0A9-E50E24DCCA9E" // UART service UUID
#define CHARACTERISTIC_UUID_RX "6E400002-B5A3-F393-E0A9-E50E24DCCA9E"
#define CHARACTERISTIC_UUID_TX "6E400003-B5A3-F393-E0A9-E50E24DCCA9E"

//Pines de sensores analogicos.
const int PINTEMPERATURA = 32;
const int PINAGUA = 35;

//Pin del relee (electrovalvula).
const int PINRELE = 23;

//-------VARIABLES GLOBALES SENSORES
double temperatura;
int x, y, z;
uint16_t r, g, b, c, colorTemp, lux;
int hayAlgoEnPileta = 0;
char nombreColor[13];
int valorSensorAgua;

//Constructor del acelerometro.
ADXL345 adxl = ADXL345();
const int SENSIBILIDAD_ACELEROMETRO = 5;

//Tareas, concepto similar a Thread, el ESP32 tiene 2 nucleos, por lo tanto puedo tener threads en mas de un nucleo.
TaskHandle_t Task1;
TaskHandle_t Task2;

//Constructor del termometro.
OneWire oneWire(PINTEMPERATURA);
DallasTemperature tempSensor(&oneWire);

//Constructor del colorimetro.
Adafruit_TCS34725 tcs = Adafruit_TCS34725(TCS34725_INTEGRATIONTIME_700MS, TCS34725_GAIN_1X);
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

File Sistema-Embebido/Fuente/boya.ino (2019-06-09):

//-------LIBRERIAS

//Wifi y HTTPClient
#include "WiFi.h"
#include "HTTPClient.h"

//Bluetooth
#include <BLEDevice.h>
#include <BLEServer.h>
#include <BLEUtils.h>
#include <BLE2902.h>

//Termometro
#include "OneWire.h"
#include "DallasTemperature.h"

//Acelerometro
#include "SPI.h"
#include "Wire.h"
#include "SparkFun_ADXL345.h"

//Pantalla
#include "PCD8544.h"
#include "driver/gpio.h"
static PCD8544 lcd=PCD8544(14,13,27,26,15);

//Colorimetro
#include "Adafruit_TCS34725.h"
#include "ColorConverterLib.h"

//C
#include "stdlib.h"
#include "string.h"

//Constantes para mensajes Bluetooth
int const ORDEN_CLORO = 1;
int const ORDEN_MOTOR = 2;
int const ORDEN_WIFI = 3;
int const ORDEN_GPS = 4;
int const ORDEN_GPSAUTO = 5;


//-------CONFIGURACIONES GLOBALES

//Parametros de la conexion wifi.
char* ssid = "JORGE 1";
char* password = "ONICONARO1";

//Bluetooth
BLEServer *pServer = NULL;
BLECharacteristic * pTxCharacteristic;
bool deviceConnected = false;
bool oldDeviceConnected = false;
uint8_t txValue = 0;

//Estos numeros se frutean. https://www.uuidgenerator.net/
#define SERVICE_UUID           "6E400001-B5A3-F393-E0A9-E50E24DCCA9E" // UART service UUID
#define CHARACTERISTIC_UUID_RX "6E400002-B5A3-F393-E0A9-E50E24DCCA9E"
#define CHARACTERISTIC_UUID_TX "6E400003-B5A3-F393-E0A9-E50E24DCCA9E"

//Pines de sensores analogicos.
const int PINTEMPERATURA = 32;
const int PINAGUA = 36;

//-------VARIABLES GLOBALES SENSORES
double temperatura;
int x, y, z;
uint16_t r, g, b, c, colorTemp, lux;
char nombreColor[13];
int valorSensorAgua;

//Constructor del acelerometro.
ADXL345 adxl = ADXL345();

//Tareas, concepto similar a Thread, el ESP32 tiene 2 nucleos, por lo tanto puedo tener threads en mas de un nucleo.
TaskHandle_t Task1;
TaskHandle_t Task2;

//Constructor del termometro.
OneWire oneWire(PINTEMPERATURA);
DallasTemperature tempSensor(&oneWire);

//Constructor del colorimetro.
Adafruit_TCS34725 tcs = Adafruit_TCS34725(TCS34725_INTEGRATIONTIME_700MS, TCS34725_GAIN_1X);

//Variables que corresponden a las lineas de la pantalla.
char l1[21] = "";
char l2[21] = "";
char l3[21] = "";
char l4[21] = "";
char l5[21] = "";
char l6[21] = "";

//Variable con los datos que se van a enviar por Bluetooth.
char datosBluetooth[51] = "";

//Deteccion movimiento beta jaja.
int xyz;

void separarPorPuntoYComa(char datos[][30], const char* msg)
{
    int i = 0;
    char *pt;
    pt = strtok((char*)msg,";");
    while (pt != NULL) 
    {
        strcpy(datos[i], pt);
        pt = strtok (NULL, ";");
        i++;
    }
}

//Tratamiento de los mensajes recibidos por Bluetooth.
void tratarMensajeRecibidoBluetooth(const char* msg)
{
  int const comando = msg[0] - '0';
  char datos[5][30];
  separarPorPuntoYComa(datos, msg); // Al recibir datos EJ: 1;xxxx;xxxxxxx;xxxxxx.
  if(comando == ORDEN_CLORO)
  {
    Serial.println(msg);
    strcpy(l6, &msg[2]);
  } else if(comando == ORDEN_MOTOR){
    Serial.println(msg);
  } else if(comando == ORDEN_WIFI){
    Serial.println(msg);
  } else if(comando == ORDEN_GPS){
    Serial.println(msg);
  } else if (comando == ORDEN_GPSAUTO){
    WiFi.begin(datos[1], datos[2]);
    Serial.println("Wifi conectado");
    //Ver esto https://opencagedata.com/ para pasar de latitud longitud a texto.
  }
  
}

//Clase para el envío de datos por bluetooth.
class Servidor: public BLEServerCallbacks 
{
    void onConnect(BLEServer* pServer) 
    {
      deviceConnected = true;
    };

    void onDisconnect(BLEServer* pServer) 
    {
      deviceConnected = false;
    }
};

//Clase para la recepción de datos por bluetooth.
class Cliente: public BLECharacteristicCallbacks 
{
    void onWrite(BLECharacteristic *pCharacteristic) 
    {
      //El valor a recibir es un string, si mando otro valor que no sea string aparece raro.
      std::string rxValue = pCharacteristic->getValue();

      if (rxValue.length() > 0) 
      {
        //Serial.print("Valor recibido: ");
        const char* valor = rxValue.c_str();
        tratarMensajeRecibidoBluetooth(valor);
      }
    }
};

//Inicializaciones.
void setup() 
{
  //-------INICIALIZACION DE PANTALLA.
  gpio_set_direction(GPIO_NUM_23, GPIO_MODE_OUTPUT);
  gpio_set_level(GPIO_NUM_23, 1);
  lcd.begin(84, 48);
  lcd.clear();
  
  //Velocidad puerto serial.
  Serial.begin(115200);

  //-------INICIALIZACION DEL TERMOMETRO. 
  tempSensor.begin();
  mostrar(0, 0, "DS18B20 ON");

  //-------INICIALIZACION DEL COLORIMETRO.
  tcs.begin();
  mostrar(0, 1, "TCS34725 ON");

  //-------INICIALIZACION DE ACELEROMETRO.
  adxl.powerOn();            
  adxl.setRangeSetting(16);

  mostrar(0, 2, "ADXL345 ON");

  //-------INICIALIZACION DEL BLUETOOTH.
  // Inicializacion del BLE con nombre.
  BLEDevice::init("ESP32");

  // Creacion del servidor.
  pServer = BLEDevice::createServer();
  pServer->setCallbacks(new Servidor());
  BLEService *pService = pServer->createService(SERVICE_UUID);
  pTxCharacteristic = pService->createCharacteristic(CHARACTERISTIC_UUID_TX,BLECharacteristic::PROPERTY_NOTIFY);          
  pTxCharacteristic->addDescriptor(new BLE2902());
  BLECharacteristic * pRxCharacteristic = pService->createCharacteristic(CHARACTERISTIC_UUID_RX,BLECharacteristic::PROPERTY_WRITE);
  pRxCharacteristic->setCallbacks(new Cliente());
  pService->start();
  pServer->getAdvertising()->start();
  Serial.println("Esperando la conexion de un cliente.");

  adaptacionColor(r, g, b, c);
  
  //Asignacion de la tarea para el core 1.
  xTaskCreatePinnedToCore(Task1Core1, "Task1", 10000, NULL, 1, &Task1, 0);     

  //Asignacion de la tarea para el core 1.
  xTaskCreatePinnedToCore(Task2Core1, "Task2", 10000, NULL, 1, &Task2, 0);  
  delay(2000); // Para observar los ON.
}

//https://www.luisllamas.es/arduino-sensor-color-rgb-tcs34725/
void adaptacionColor(uint16_t red, uint16_t green, uint16_t blue, uint16_t c)
{
  uint32_t sum = c;
  float r, g, b;
  r = red; r /= sum;
  g = green; g /= sum;
  b = blue; b /= sum;
 
  // Escalar rgb a bytes
  r *= 256; g *= 256; b *= 256;

  double hue, saturation, value;
  ColorConverter::RgbToHsv(static_cast<uint8_t>(r), static_cast<uint8_t>(g), static_cast<uint8_t>(b), hue, saturation, value);
  hue*=360;
  if (hue < 15)
    strcpy(nombreColor, "Rojo");
  else if (hue < 45)
    strcpy(nombreColor, "Naranja");
  else if (hue < 90)
    strcpy(nombreColor, "Amarillo");
  else if (hue < 150)
    strcpy(nombreColor, "Verde");
  else if (hue < 210)
    strcpy(nombreColor, "Cyan");
  else if (hue < 270)
    strcpy(nombreColor, "Azul");
  else if (hue < 330)
    strcpy(nombreColor, "Magenta");
  else
    strcpy(nombreColor, "Rojo");
  //Serial.println(hue);
}
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

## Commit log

2019-04-19 Subida de directorios.
2019-04-27 Pruebas de los sensores con Arduino
2019-05-02 Envío de datos por Bluetooth.
2019-05-02 Prueba de recepción vía Bluetooth
2019-05-05 Integración de SensoresBluetoothWIFILCD
2019-05-07 Subida de diagramas.
2019-05-15 Subida de diagramas, falta juntar los diagramas funcionales que se encuentran sueltos.
2019-05-18 Drop a lo negro de color
2019-05-18 codigo de SE unificado y funcionando, procesamiento de datos string recibidos via bluetooth
2019-06-04 se agrega mock de datos de temperatura y color del agua en tab de estado; se agrega mock para encender motor en tab de estado; se agrega mock de activacion de notificacion de caidas en tab de configu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
2019-06-05 Boton de busqueda de dispositivos, visualizacion de los mismos e intento de conexion; Encender el bluetooth desde la app; Logica basica para envio y recepcion de datos via bluetooth
2019-06-05 correccion de diagramas
2019-06-08 Ahora los diagramas se encuentran dentro de la carpeta Sistema-Embebido. Y se agrega el fritzing version 1 del proyecto.
    [Fritzing.fzz]
2019-06-09 [iOS] Manejo del sensor GPS y Bluetooth
    Ahora se puede enviar los datos de la conexión Wifi y la ubicación introducida a mano o tomada automáticamente del sensor del celular.
2019-06-09 [SE] Tratamiento de Mensajes Bluetooth
    Ahora al recibir un mensaje bluetooth del formato x;xxxx;xxxxxxx;xxxxx cada dato entre el separador punto y coma se guarda en un vector de string para que sea mas fácil su manejo.
2019-06-09 [SE] División de código
    Se divide el código en 3 archivos y además se implementa un conversor de latitud, longitud a texto (ciudad) para usar posteriormente en API Clima.
2019-06-12 [iOS] Señal de activación del servo
2019-06-12 [SE] Activación del servo y relee por BT.
2019-06-13 test conexion y enviar apretando el boton de switch
2019-06-15 agrego logs y cambio pin de sensor de lluvia
2019-06-16 [SE] Ajuste general División de código Prueba integral de todos los sensores. Prueba integral de todos los actuadores. Funcionamiento del relee junto a la valvula. Simulación de llamada API Clima.
2019-06-16 [iOS] Ahora muestra los datos del sensor de lluvia y el color del agua. Se removió la sección de estadísticas.
2019-06-18 [iOS] Ahora el acelerómetro sirve para seleccionar opciones.
2019-06-22 subida inicial de informe final
2019-06-29 [SE] Puesta a punto de todas las funciones. Faltan opcionales de APIs GeoLocalizacion y Clima, actualmente funciona con una API Mock.
2019-06-29 [iOS] Puesta a punto de todas las funciones.
2019-07-01 [Diagramas] Actualizacion del Fritzing
    [Fritzing.fzz]
2019-07-03 [Diagramas] Actualizacion de Diagramas
2019-07-03 [Informe Final] Preview de Informe Final.
2019-07-03 [SE] Correcciones sobre la hora y activacion del motor segun lluvia.
2019-07-03 [SE] Correcciones sobre la logica del motor prioridad usuario / automatismo.
2019-07-04 [SE] Lógica de dispensado. No probado todavía.
2019-07-06 [SE] Cambios El archivo sensores.h se remueve ahora es colorimetro.h. Se ajusta la sensibilidad del acelerometro para probar mas facilmente. Se elimina la primera linea en la pantalla del nombre de p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
2019-07-08 [SE] Se agrega lógica del buzzer.
    [parametros.h, principal.ino]
2019-07-08 [Diagramas] Diagrama de estados se cambio servo por motor. Diagramas Funcional y en Bloques se vuelve a incluir el buzzer.
2019-07-09 [SE] Se agrega inicializacion del buzzer que faltaba.
    [principal.ino]
2019-07-09 [Diagramas] Fritzing version final con buzzer.
    [Fritzing.fzz]
2019-07-09 [Informe Final] Agregado los nuevos diagramas
    Además de los componentes resistor, transistor y protoboard utilizados en el proyecto.
2019-07-09 [Diagramas] Actualizacion
    Inclusión de buzzer en software, físico y funcional.
2019-07-09 [Diagramas] Actualizacion de Diagrama en Bloques
2019-07-09 [Diagramas] Actualizacion Diagrama de Estados
2019-07-10 [Diagramas] Actualizacion Fritzing.fzz
    [Fritzing.fzz]
2019-07-10 [SE] Se remueve vDelayTask innecesario de 1ms en el nucleo principal
2019-07-10 Rama Entrega Final.
    [Fritzing.fzz]
2019-07-13 correccion diagrama de software
